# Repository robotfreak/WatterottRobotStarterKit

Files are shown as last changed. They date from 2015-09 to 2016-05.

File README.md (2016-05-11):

# Watterott Robot Starter Kit v2 (de)

Arduino Bibliothek und Beispiele für das Watterott Robot Starter Kit v2

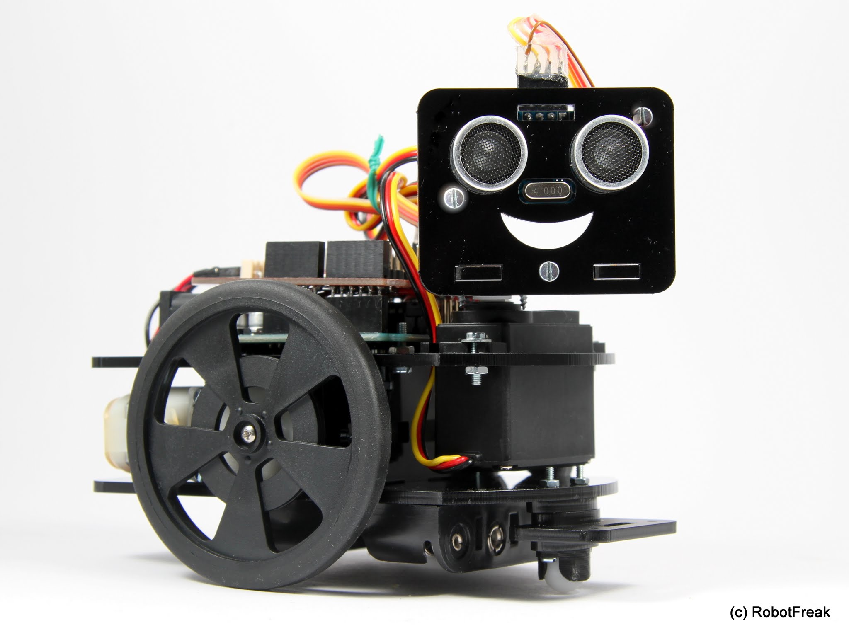
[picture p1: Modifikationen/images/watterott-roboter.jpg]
Watterott Roboter


## Basis Ausstattung:
* Watterott Starter Robot Kit (WSRK) Plexiglas Chassis, Motoren und Räder
* Arduino Uno 
* Arduino Motor Shield 
* Sharp GP2Y0A21YK0F Infrarot Distanz-Sensor an Pin A3
* Servo an Pin D5
* USB Kabel

## optionale Ausstattung:
* optional HC-SR04 Ultrascall Distanz Sensor an Pin D6, D7
* optional Pololu QTR-3A analoger Linien-Sensor an Pin A0,A1,A2
* optional Adafruit Bluefruit EZ-Link Modul
* Arduino Pro 5V anstelle Arduino Uno für einfachere Bluetooth Anbindung
* FTDI kompatibles USB serielles Modul/Kabel für Arduino Pro

## Modifikationen

* [Motoren entstören](Modifikationen/Motoren-Entstoeren-Mod.MD)
* [stärkere Motoren](Modifikationen/Staerkere-Motoren-Mod.MD)
* [Servo Stromversorgung](Modifikationen/Servo-Stromversorgungs-Mod.MD)
* [Sharp Stromversorgung](Modifikationen/Sharp-Sensor-Mod.MD)
* [Stromversorgung](Modifikationen/Stromversorgungs-Mod.MD)

## Erweiterungen

* [Ultraschall Sensor](Erweiterungen/Ultraschallsensor-Erweiterung.MD)
* [Linien Sensor](Erweiterungen/Liniensensor-Erweiterung.MD)
* [Bluetooth](Erweiterungen/Bluetooth-Erweiterung.MD)

## Links

Für weitere Informationen  über Erweiterungen oder Modifications des Watterott Starter Robot
besuchen sie: http://www.robotfreak.de

Für Informationen zum Kauf des Watterott Starter Robot Kit (WSRK)
besuchen sie:  http://www.watterott.com/de/StarterKit-Roboter

# Watterott Robot Starter Kit v2 (en)

Arduino Library &amp; Examples for the Watterott Robot Starter Kit v2

## Basic Parts:
* Watterott Starter Robot Kit (WSRK) acrylic chassis, motors and wheels
* Arduino Uno 
* Arduino Motor Shield 
* Sharp GP2Y0A21YK0F Infrared distance sensor connected to A3
* Servo connected to Pin D5
* USB cable

## Optional Parts:
* optional HC-SR04 Ultrasonic distance sensor connected to pin D6, D7
* optional Pololu QTR-3A analog Line sensor connected to A0,A1,A2
* optional Adafruit Bluefruit EZ-Link Module
* Arduino Pro 5V instead of Arduno Uno for easy Bluetooth connection
* FTDI compatible USB serial module/cable for Arduino Pro

## Modifikations

* [Motors](Modifikationen/Motoren-Entstoeren-Mod.MD)
* [More powerfull motors](Modifikationen/Staerkere-Motoren-Mod.MD)
* [Servo power supply](Modifikationen/Servo-Stromversorgungs-Mod.MD)
* [Sharp power supply](Modifikationen/Sharp-Sensor-Mod.MD)
* [Power supply](Modifikationen/Stromversorgungs-Mod.MD)

## Expansions

* [Ultrasonic sensor](Erweiterungen/HC-SR04-Erweiterung.MD)
* [Line sensor](Erweiterungen/Liniensensor-Erweiterung.MD)
* [Bluetooth](Erweiterungen/Bluetooth-Erweiterung.MD)

## Links

For information about expansions or modifications of the Watterott Starter Robot
visit http://www.robotfreak.de for more information

For information about buying the Watterott Starter Robot Kit (WSRK)
visit http://www.watterott.com/de/StarterKit-Roboter

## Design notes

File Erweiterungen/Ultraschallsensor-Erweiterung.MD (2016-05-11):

# Ultraschallsensor Erweiterung

Der Ultraschall Sensor kann anstelle des Sharp Infrarotsensors eingesetzt werden. Der Sensor hat einen breiteren Erfassungswinkel. Auf das Scannen der Umgebung mit dem Servo kann weitestgehend verzichtet werden.

## Was wird benötigt?

* HC-SR04 Ultraschallsensor
* 4-polige Buchsenleisten
* 4-polige Stiftleiste
* 4 Drähte 15cm lang
* Plexiglas Halterung (im Roboter Starer Kit enthalten)
* Lötkolben, Seitenschneider

## Durchführung

Der Sensor wird gemäß Verdrahtungs Schema verdrahtet und mit der Plexiglas Halterung am Servo Horn befestigt

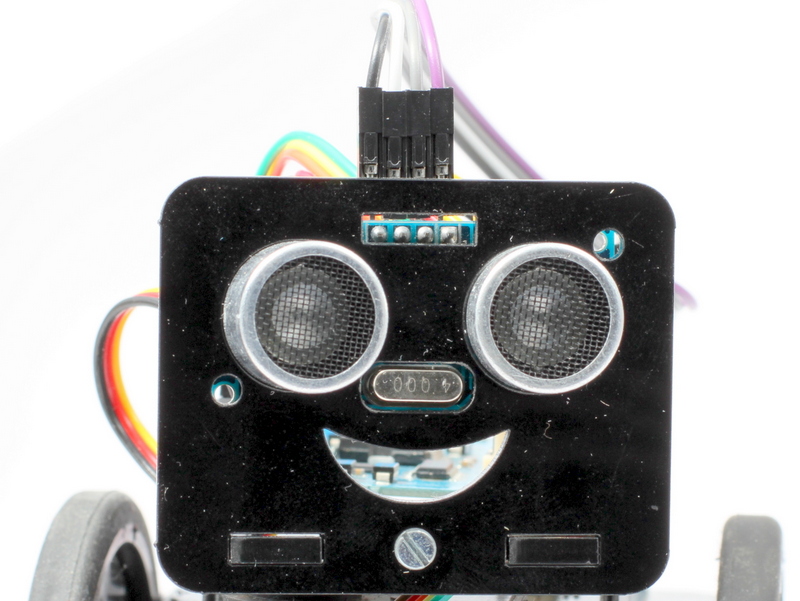
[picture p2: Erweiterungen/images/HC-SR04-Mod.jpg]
Sensor


## Verdrahtung

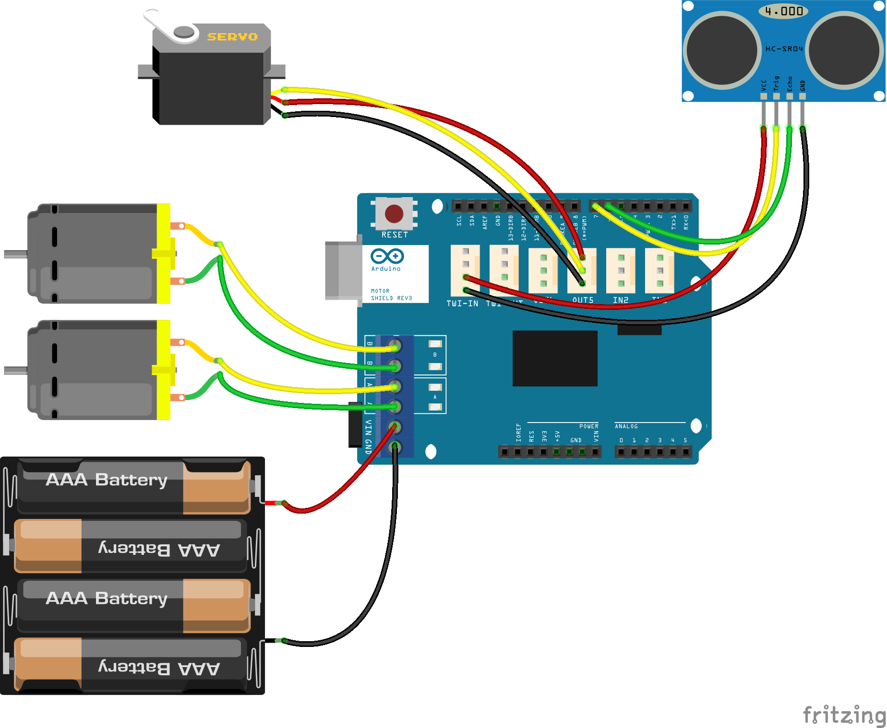
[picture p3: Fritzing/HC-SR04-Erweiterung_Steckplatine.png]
Verdrahtung


## Arduino Sketch

Die Funktionen zum Auslesen des Sensors sind Teil der Watterott Roboter Starter Kit (WRSK) Bibliothek.

Das Beispiel Sketch zum Kollionsvermeider (examples/ObstacleAvoiding) 

```arduino
/*
  ObstacleAvoiding.ino - Watterott Starter Robot Kit (WSRK)
  Author: RobotFreak www.robotfreak.de/blog
  Copyright (c) 2015 RobotFreak All Rights Reserved
 
  For information about the Watterott Starter Robot Kit (WSRK)
  visit http://www.watterott.com/de/StarterKit-Roboter
 
  The minimum circuit:
  * Watterott Starter Robot Kit (WSRK) Arduino Uno + Arduino Motor Shield 
  * Sharp GP2D12 or GP2D120 Infrared distance sensor connected to A3
  * or HC-SR04 Ultrasonic distance sensor connected to pin 6, 7
  * USB cable

  Alternative circuit:
  * Watterott Starter Robot Kit (WSRK) Arduino Pro + Arduino Motor Shield 
  * FTDI compatible USB serial module/cable
  * Sharp GP2D12 or GP2D120 Infrared distance sensor connected to A3
  * or HC-SR04 Ultrasonic distance sensor connected to pin 6, 7
  * optional Adafruit Bluefruit EZ-Link Module connected to FTDI connector

 */
#include <inttypes.h>
#include <Servo.h>
#include "iomapping.h"
#include <WRSK_UltrasonicSensor.h>
#include <WRSK_MotorControl.h>

#define DEBUG_LEVEL 2

#define LOW_SPEED 50
#define MID_SPEED 70
#define TOP_SPEED 100

WRSK_MotorControl motors( m1DirectionControl, m1SpeedControl, m2DirectionControl, m2SpeedControl, DEBUG_LEVEL);
WRSK_UltrasonicSensor us(usEchoPin, usTriggerPin, DEBUG_LEVEL);

int speed_l;
int speed_r;
int dly;
float distance;
int debugLevel = DEBUG_LEVEL;

Servo SensorServo;  // Mit diesem Element wird der Servo gesteuert

void setup() {

  Serial.begin(38400);                 // Sets the baud rate to 38400
  speed_l = 0;
  speed_r = 0;
  // Servo initialiseren und auf 90° stellen
  SensorServo.attach( servoPin );
  SensorServo.write( 90 );
  delay( 500 );

  Serial.println("WMR-SHR obstacle Avoiding Version 1.0");   

  distance = us.read();  // get distance
  while (distance > 10.0)
  {
    distance =  us.read();  // get distance
    delay(100);
  }
  Serial.println("Let's go");
}

void loop()
{
  int i;

  distance =  us.read();  // get distance

  if (distance > 0.0)
  {
    if (distance <= 10.0)
    {
      motors.driveWheels(0,0);
      delay(500);
      speed_l = -MID_SPEED;
      speed_r = MID_SPEED;
      dly = 5;
      do {
        distance =  us.read();  // get distance
        delay(40);
        motors.driveWheels(speed_l, speed_r);
        //      motors.driveWheelsRamp(speed_l, speed_r, dly);
      } 
      while(distance < 20.0);  
      speed_l = 0;
      speed_r = 0;
      motors.driveWheels(speed_l,speed_r);
      //    motors.driveWheelsRamp(speed_l, speed_r, dly);
      delay(500);
    }
    else if (distance < 30.0)
    {
      speed_l = MID_SPEED;
      speed_r = MID_SPEED;
    }
    else
    {
      speed_l = TOP_SPEED;
      speed_r = TOP_SPEED;
    }
    dly = 10;
    motors.driveWheels(speed_l, speed_r);
    //  motors.driveWheelsRamp(speed_l, speed_r, dly);
  }

  delay(40);

}
```

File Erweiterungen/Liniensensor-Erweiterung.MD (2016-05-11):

# Liniensensor Erweiterung

Mit dieser  Erweiterung kann der Roboter einen schwarzen Linie auf weißem Unterrund folgen

## Was wird benötigt?

* Pololu QTR-3A Liniensensor (analog)
* 5 polige Buchsenleiste 
* 5 polige Stiftleiste 
* 2 polige Stiftleiste 
* 2 Schrauben M2x15, 4 Muttern M2
* Lötkolben, Seitenschneider, Dremel
* schwarzes Isolier Klebeband 10mm breit
* Plexiglas Halterung (im Roboter Kit enthalten)

## Durchführung

* Es müssen die beiden Lötbrücken SNS1 und SNS2 am Motor Shield entfernt werden.
* Die Verbindung Sensor / Arduino Shield erfolgt mit den Drähten, Buchsen- und Stiftleisten
* Der Sensor wird mit den M2 Schrauben und Muttern und der Plexiglas Halterung am Roboter Starter Kt befestigt 

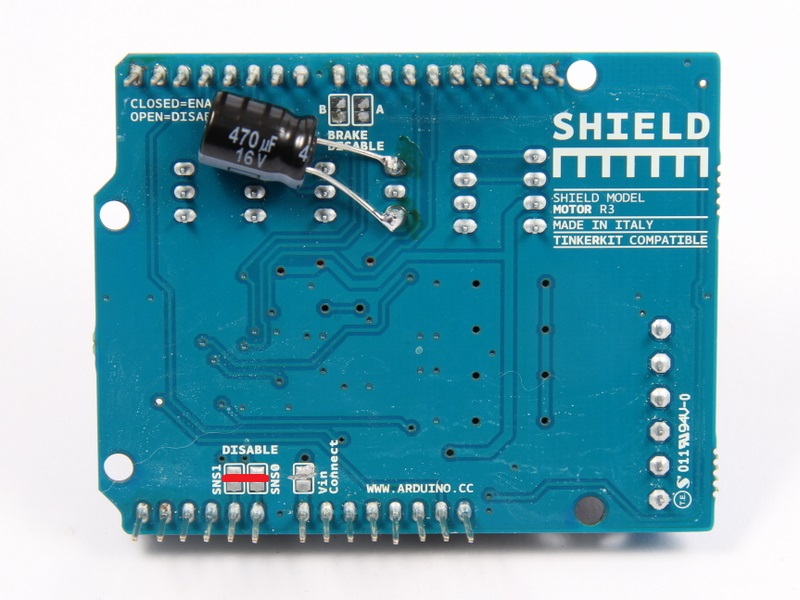
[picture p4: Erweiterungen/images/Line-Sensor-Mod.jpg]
Motorshield Mod

 
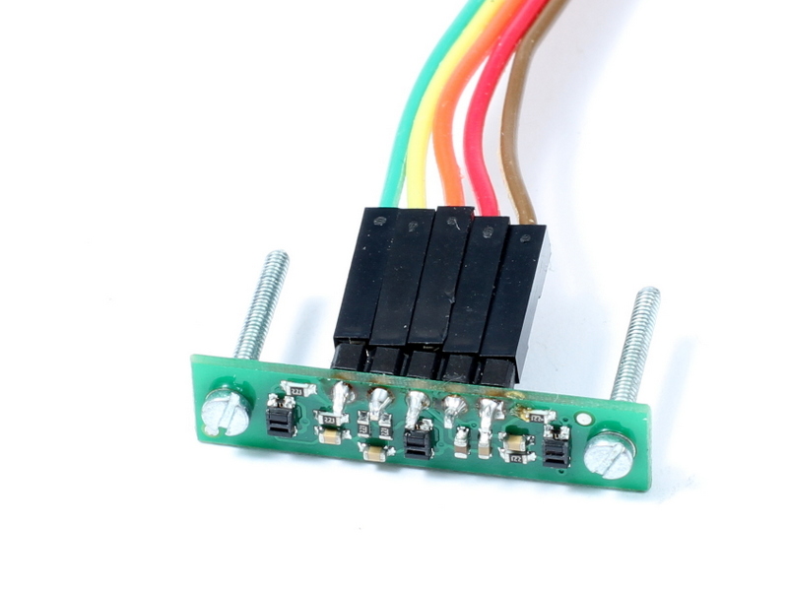
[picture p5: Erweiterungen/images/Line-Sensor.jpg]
Sensor Linien-Sensor


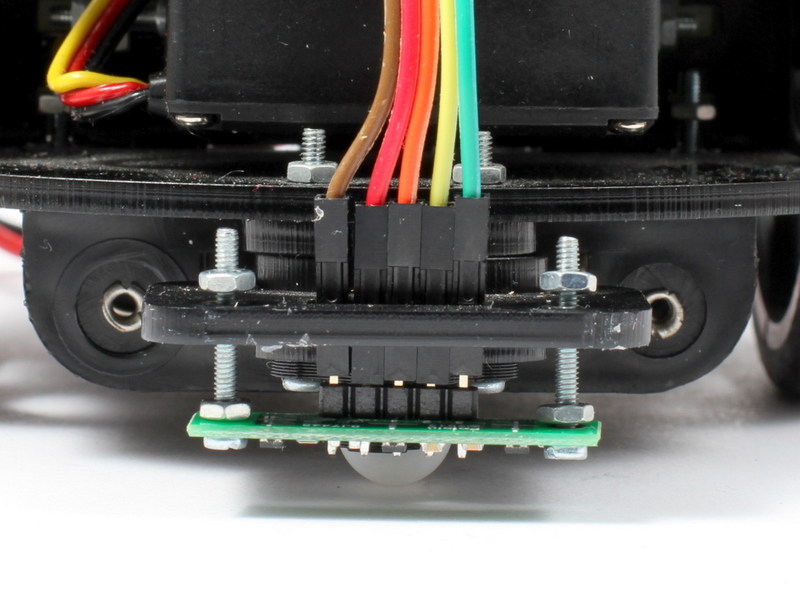
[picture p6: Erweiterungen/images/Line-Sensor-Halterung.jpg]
Sensor Halterung


## Verdrahtung

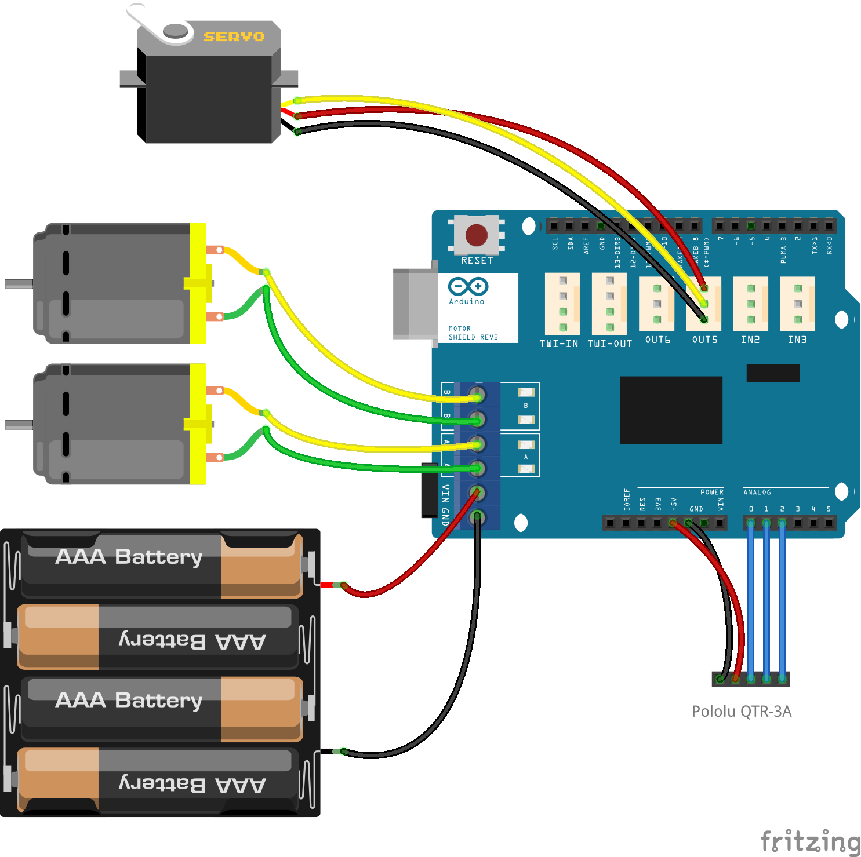
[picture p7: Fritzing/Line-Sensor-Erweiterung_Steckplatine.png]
Verdrahtung


## Arduino Sketch

Es wird die Pololu QTR Bibliothek benötigt: https://github.com/pololu/qtr-sensors-arduino

```arduino
/*
 LineFollower.ino - Watterott Starter Robot Kit (WSRK) line follower
 
  Author: RobotFreak www.robotfreak.de/blog
  Copyright (c) 2015 RobotFreak All Rights Reserved
 
  For information about the Watterott Starter Robot Kit (WSRK)
  visit http://www.watterott.com/de/StarterKit-Roboter

  The minimum circuit:
  * Watterott Starter Robot Kit (WSRK) Arduino Uno + Arduino Motor Shield 
  * Pololu QTR-3RC or QTR-3A Line sensor connected to A0,A1,A2
  * HC-SR04 Ultrasonic distance sensor connected to pin 6, 7
  * USB cable

  Alternative circuit:
  * Watterott Starter Robot Kit (WSRK) Arduino Pro + Arduino Motor Shield 
  * FTDI compatible USB serial module/cable
  * Pololu QTR-3RC or QTR-3A Line sensor connected to A0,A1,A2
  * optional Adafruit Bluefruit EZ-Link Module connected to FTDI connector
 
*/
#include <Servo.h>
#include <QTRSensors.h>
#include <PID_v1.h>
#include "iomapping.h"
#include <WRSK_UltrasonicSensor.h>
#include <WRSK_SharpSensor.h>
#include <WRSK_MotorControl.h>

#define LOW_SPEED 50
#define MID_SPEED 70
#define TOP_SPEED 100

#define BUFFERSIZE 20
#define DEFAULT_speedMultiplier 5 
//#define USE_BLUETOOTH_SERIAL2    // we use Bluetooth over Serial2

// ** GENERAL SETTINGS ** - General preference settings
#define DEBUG_LEVEL 2
int debugLevel = DEBUG_LEVEL;
boolean DEBUGGING = true; // Whether debugging output over serial is on by defauly (can be flipped with 'h' command)

WRSK_MotorControl motors( m1DirectionControl, m1SpeedControl, m2DirectionControl, m2SpeedControl, DEBUG_LEVEL);

int speedMultiplier = DEFAULT_speedMultiplier; // Default speed setting. Uses a range from 1-10 

// No config required for these parameters
unsigned long stopTime=millis(); // used for calculating the run time for motors

//Define Variables we'll be connecting to
double Setpoint, Input, Output;

//Define the aggressive and conservative Tuning Parameters
double aggKp=4, aggKi=0.2, aggKd=1;
double consKp=1, consKi=0.0, consKd=0.0;
//double consKp=1, consKi=0.05, consKd=0.25;

//Specify the links and initial tuning parameters
PID myPID(&Input, &Output, &Setpoint, consKp, consKi, consKd, DIRECT);

Servo myServo;

void setup() 
{
  myServo.attach(servoPin);
  myServo.write(90);

  Serial.begin(38400);
#ifdef USE_BLUETOOTH_SERIAL2
  Serial2.begin(115200);
#endif
  if (debugLevel) { Serial.println("MURCS Line Follower V1.0");  }
  initLineFollow();
//  initLineFollowPID();
  
} 

// Stop the bot
void stopBot() 
{
  motors.driveWheels(0,0);
  if (debugLevel){ Serial.println("Stopping both wheels"); 
  }
  serialReply("i", "st"); // Tell the phone that the robot stopped
}

// sensors 0 through 2 are connected to analog inputs 0 through 2, respectively
QTRSensorsRC qtr((unsigned char[]) {line1Pin, line2Pin, line3Pin}, 
  NUM_LINESENSORS);
unsigned int sensorValues[NUM_LINESENSORS];

void initLineSensors(int debugLevel)
{
  delay(1000);
  for (int i = 0; i < 10; i++)  // make the calibration take about 1.25 seconds
  {
    qtr.calibrate();       // reads all sensors 10 times at 2.5 ms per six sensors (i.e. ~25 ms per call)
    motors.driveWheels(-LOW_SPEED,LOW_SPEED);
  }
  motors.driveWheels(0,0);
  delay(500);
  for (int i = 0; i < 15; i++)  // make the calibration take about 2.5 seconds
  {
    qtr.calibrate();       // reads all sensors 10 times at 2.5 ms per six sensors (i.e. ~25 ms per call)
    motors.driveWheels(LOW_SPEED,-LOW_SPEED);
  }
  motors.driveWheels(0,0);
  delay(500);
  for (int i = 0; i < 10; i++)  // make the calibration take about 1.25 seconds
  {
    qtr.calibrate();       // reads all sensors 10 times at 2.5 ms per six sensors (i.e. ~25 ms per call)
    motors.driveWheels(-LOW_SPEED,LOW_SPEED);
  }
  motors.driveWheels(0,0);
  delay(500);
  // print the calibration minimum values measured when emitters were on
  if (debugLevel > 1)
  {
    for (int i = 0; i < NUM_LINESENSORS; i++)
    {
      Serial.print(qtr.calibratedMinimumOn[i]);
      Serial.print(' ');
    }
    Serial.println();
  
    // print the calibration maximum values measured when emitters were on
    for (int i = 0; i < NUM_LINESENSORS; i++)
    {
      Serial.print(qtr.calibratedMaximumOn[i]);
      Serial.print(' ');
    }
    Serial.println();
    Serial.println();
  }
  delay(1000);
}

unsigned int  readLineSensors(int debugLevel)
{
  // read calibrated sensor values and obtain a measure of the line position from 0 to 5000
  // To get raw sensor values, call:
  //  qtra.read(sensorValues); instead of unsigned int position = qtra.readLine(sensorValues);
  unsigned int position;
  static int count = 0;

//  qtr.read(sensorValues);
  position = qtr.readLine(sensorValues);
  
  if (debugLevel > 1)
  {
  // print the sensor values as numbers from 0 to 1000, where 0 means maximum reflectance and
  // 1000 means minimum reflectance, followed by the line position
    for (unsigned char i = 0; i < NUM_LINESENSORS; i++)
    {
      Serial.print(sensorValues[i]);
      Serial.print('\t');
    }
    //Serial.println(); // uncomment this line if you are using raw values
    Serial.println(position); // comment this line out if you are using raw values
  }
  if (count > 10)
  {
//    Serial2.write((position >> 8) & 0xFF);
//    Serial2.write(position & 0xFF);
    count = 0;
  }
  return position;
}

void initLineFollow()
{
//  myServo.write(90);
  initLineSensors(debugLevel);
}

void initLineFollowPID()
{
//  myServo.write(90);
  initLineSensors(debugLevel);
  Input = 0.0;
  Setpoint = 0.0;
  //tell the PID to range between -50 and 50 
  myPID.SetOutputLimits(-2000, 2000); 
  //turn the PID on
  myPID.SetMode(AUTOMATIC);
}

// Replies out over serial and handles pausing and flushing the data to deal with Android serial comms
void serialReply(char* sensorname, char* tmpmsg) 
{
#ifdef USE_BLUETOOTH_SERIAL2
  Serial2.print(sensorname);
  Serial2.print(":");
  Serial2.println(tmpmsg); // Send the message back out the serial line
  //Wait for the serial debugger to shut up
  delay(200); //this is a magic number
  Serial2.flush(); //clears all incoming data
#else
  Serial.print(sensorname);
  Serial.print(":");
  Serial.println(tmpmsg); // Send the message back out the serial line
  //Wait for the serial debugger to shut up
  delay(200); //this is a magic number
  Serial.flush(); //clears all incoming data
#endif
}

// Check if enough time has elapsed to stop the bot and if it is safe to proceed
void checkIfStopBot() 
{
  if (stopTime < millis()) 
  {
    stopBot();
  }
}

void doLineFollow()
{
  int speed_l, speed_r;
  unsigned int position;

  position = readLineSensors(debugLevel);

  if (position < 500)
  {  // far to the right                                    
    if (debugLevel > 2) { Serial.println("far to the right");}
    speed_l = MID_SPEED;
    speed_r = -LOW_SPEED;
  }
  else if (position > 1500)
  {  // far to the left
    if (debugLevel > 2) { Serial.println("far to the left");}
    speed_l = -LOW_SPEED;
    speed_r = MID_SPEED;
  }
  else
  {  // centered on line 
    if (debugLevel > 2) { Serial.println("on line");}
    speed_l = MID_SPEED;
    speed_r = MID_SPEED;
  }
  stopTime = motors.driveWheels(speed_l, speed_r);
  delay(20); 
}

void doLineFollowPID()
{
  int speed_l, speed_r, speedDiff;
  int position;

  position = readLineSensors(0);
  Input = position - 2000.0;
  myPID.Compute();

  speedDiff = map(abs((int)Output), -2000, 2000, -50, 50);
//  if (Output < 0.0)
//  speedDiff = -speedDiff;
  if (debugLevel > 1) 
  {
    Serial.print("Input: ");
    Serial.print(Input, DEC);
    Serial.print(" Output: ");
    Serial.print(Output, DEC);
    Serial.print(" SDiff: ");
    Serial.println(speedDiff, DEC);
  }
//  speedDiff = (int) power_difference;
  // Compute the actual motor settings.  We never set either motor
  // to a negative value.
  const int max = TOP_SPEED;
  if(speedDiff > max)
      speedDiff = max;
  if(speedDiff < -max)
      speedDiff = -max;
 
  if(speedDiff < 0)
     stopTime = motors.driveWheels(max+speedDiff, max);
  else
     stopTime =  motors.driveWheels(max, max-speedDiff);
  delay(40); 
}

// Main loop running at all times
void loop() 
{
  doLineFollow();
  checkIfStopBot();
}
```

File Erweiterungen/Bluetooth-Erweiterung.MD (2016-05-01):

# Bluetooth Erweiterung

Die Bluetooth Erweiterung ermöglicht die Fernbedienung des Roboter über Bluetooth. Mit dem Adafruit BLuetooth EZ-Link ist es auch möglich, den Arduino über Bluetooth zu programmieren.

## Was wird benötigt?

* Adafruit Bluetooth EZ Link Modul
* Arduino Pro 5V/16MHz
* oder 10polige Stiftleiste, 100nF Kondensator für Arduino Uno

## Durchführung

Leider funktioniert dies Erweiterung nicht so ohne weiteres mit dem Arduino Uno. Einfacher geht es mkt einem Arduino Pro. Dort kann man einfach das Bluetooth Modul an der 6-poligen FTDI -Stiftleite anstecken. fertig.

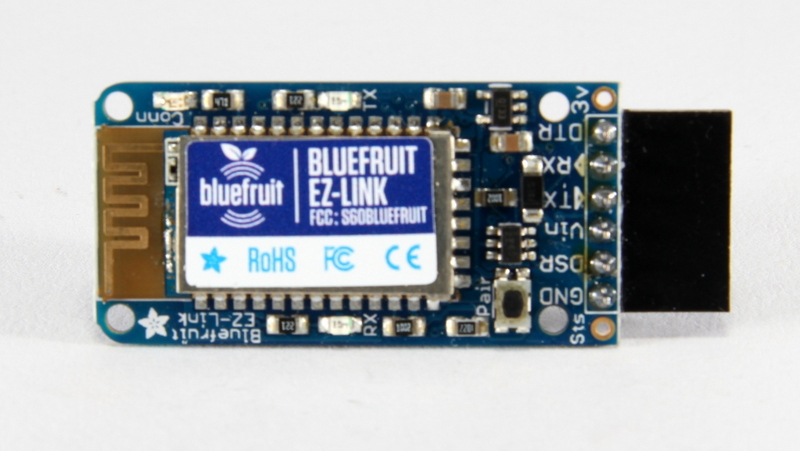
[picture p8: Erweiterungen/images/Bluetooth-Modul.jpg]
Bluetooth Bluetooth Modul


## Verdrahtung Arduino Pro

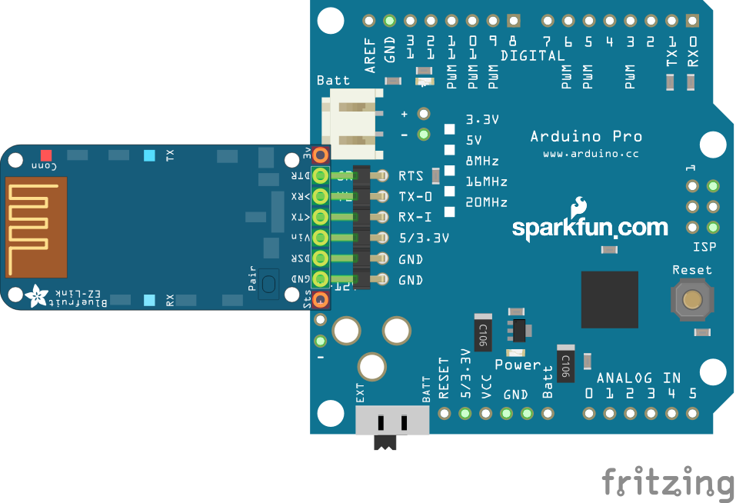
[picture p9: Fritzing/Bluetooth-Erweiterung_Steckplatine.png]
Verdrahtung Pro Verdrahtung Arduino Pro


## Verdrahtung Arduino Uno

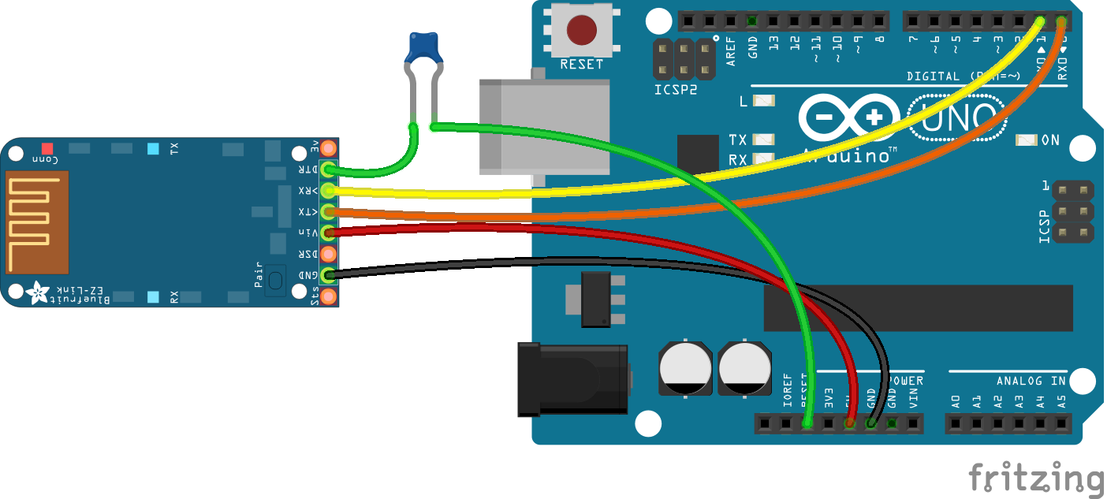
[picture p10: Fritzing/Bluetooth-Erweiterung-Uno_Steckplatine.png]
Verdrahtung Uno Verdrahtung Arduino Uno


## Arduino Sketch

t.b.c

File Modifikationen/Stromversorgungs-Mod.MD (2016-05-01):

#Stromversorgungs Modifikation

Bei dieser Variante wird die Batteriespannung mit Hilfe eines Step-Up Wandlers auf einen Wert im empfohlenen Eingangsbereich hochgeregelt und stabilisiert. Umbauten am Motor-Shield sind nicht notwendig. Ein geeigneter Step-Up Wandler ist z.B. der LM2577. Diesen gibt als fertiges Modul auf eBay, DealExtreme oder Amazon. Der Wandler generiert aus einer Eingangsspannung im Bereich von 3..30V eine regelbare Ausgangsspannung von 4..30V. Bei einem <a href="http://de.wikipedia.org/wiki/Aufw%C3%A4rtswandler">Aufwärtswandler</a> wird niedrige Eingangsspannung in eine höhere Ausgangsspannung gewandelt. Achtung, die Module können sehr leicht verwechselt werden mit Step-Down Wandlern mit LM2596 IC. Das sind <a href="http://de.wikipedia.org/wiki/Abw%C3%A4rtswandler">Abwärtswandler</a>, die aus einer größeren Eingangsspannung eine kleinere Ausgangsspannung machen.

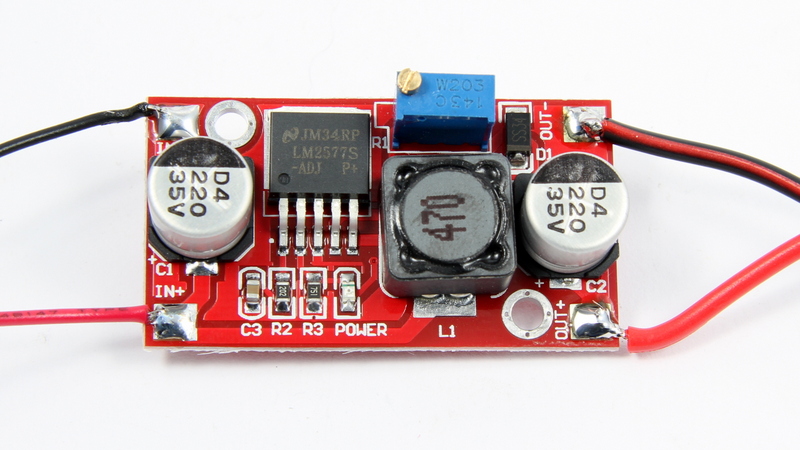
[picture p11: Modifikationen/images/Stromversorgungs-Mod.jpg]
LM2577-Modul


Der Step-Up Wandler wird zwischen Batteriefach und der Stromversorgung für das Motor Shield mit eingebaut. Bei der Gelegenheit sollte man auch gleich einen Kippschalter zum Ein-/Ausschalten des Roboters  mit einbauen. Der Step-Up Wandler wird vor dem Anschließen an das Moto-Shield, mit Hilfe des Potentiometer auf eine Ausgangsspannung von 7.5V eingestellt. Zum einen liegt dieser Wert im empfohlenen Spannungsbereich von 7..12V für das Arduino Board und Motor Shield. Zum anderen fallen am Motor Treiber ca. 1.5V  ab, während die Motoren selbst für 6V ausgelegt sind. Dadurch liegt der ideale Wert bei 7.5V. Das Step-Up Wandler Modul passt noch sehr gut auf die Unterseite des Roboters hinter das Batteriefach. Einfach mit Heißkleber festkleben.

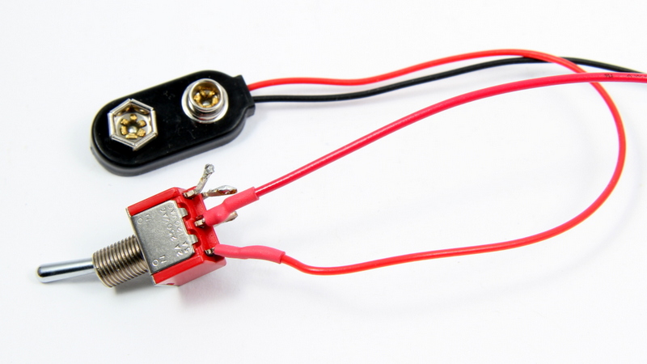
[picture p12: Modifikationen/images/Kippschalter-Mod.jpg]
Kippschalter


##Benötigte Bauteile:

* <a href="http://www.amazon.de/SainSmart-Step-up-Adjustable-Converter-3-5-30V/dp/B00KY0LW0S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">SainSmart LM2577 Power StepUp Converter</a>
* <a href="http://www.reichelt.de/Kippschalter/MS-500A/3/index.html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">optionaler Kippschalter</a>
* 10cm isolierter Draht 2 x rot, 1 x schwarz

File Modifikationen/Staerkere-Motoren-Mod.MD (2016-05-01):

#stärkere Motoren

Etwas mehr Motorleistung gefällig? Hier kommt der Tuning Tip für mehr Power. Die in den Getriebmotoren verbauten Gleichstrom Motoren sind vom Typ 130, eine gängige Größe für Motoren, die auch in vielen Spielzeug Modellen steckt. Statt der braven, stromsparenden Variante, wie sie im GM9 Getriebemotor verwendet werden, gibt es auch noch eine leistungsfähigere <a href="http://www.watterott.com/de/Brushed-DC-Motor-130-Size-6V-115kRPM-800mA-Stall">Power Variante</a>. Damit läuft der kleine Roboter gleich mal ordentlich schneller. Natürlich auf Kosten einer größeren Stromaufnahme, sprich die Akkus/Batterien sind schneller leer.

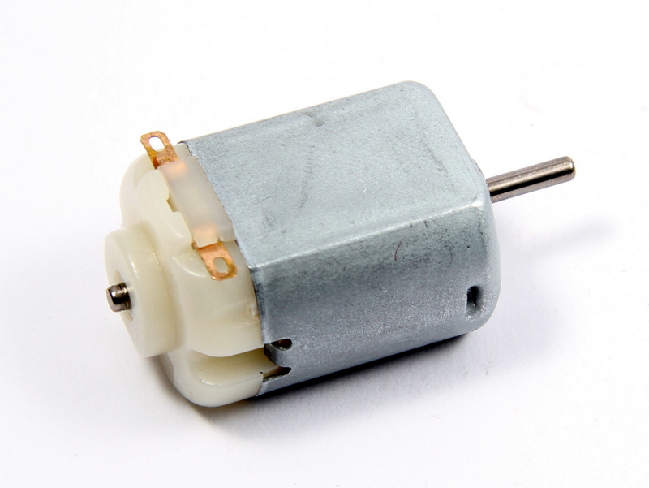
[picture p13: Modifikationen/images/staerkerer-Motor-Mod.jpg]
Motor


Für den Umbau werden die alten Motoren vom Getriebe entfernt. Die Motoren werden nur von einer Plastiklasche gehalten. Entfernt man diese vorsichtig, kann man die Motoren herausziehen. Das Motor-Ritzel lässt sich leicht mit einer Zange vom Motor abziehen und auf den neuen stärkeren Motor aufstecken. Den Motor wieder zurück in das Getriebe stecken und mit der Plastiklasche fixieren. Voila.

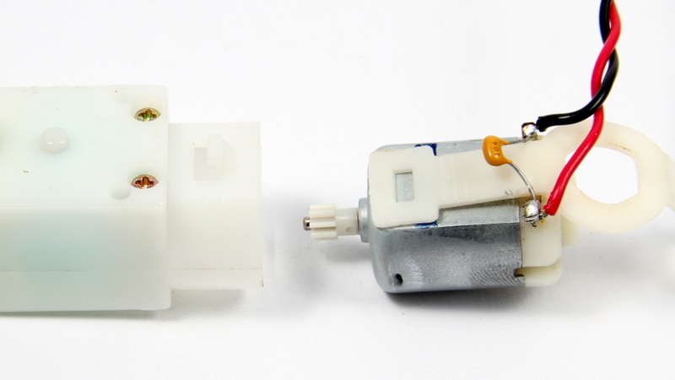
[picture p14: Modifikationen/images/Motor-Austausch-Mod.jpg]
Motor-Austausch


##Benötigte Bauteile:

* 2 x <a href="http://www.watterott.com/de/Brushed-DC-Motor-130-Size-6V-115kRPM-800mA-Stall">Watterott Brushed DC Motor 130-size 800mA stall</a>
* 2 x <a href="http://www.exp-tech.de/dc-buerstenmotor-130-size-6v-11-5krpm-800ma-stall">alternativ Exp-Tech Brushed DC Motor 130-size 800mA stall</a>

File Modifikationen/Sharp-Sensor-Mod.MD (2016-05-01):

#Sharp Sensor Modifikation

Der Infrarot Sensor (Sharp GP2Y0A21YK0F) ist eine preiswerte Möglichkeit um Entfernungen zu Objekten zu messen, die sich vor dem Roboter befinden. Leider ist das Ausgangssignal dieser Sensoren nicht sehr stabil und gibt daher keine genauen Werte zurück. Das Problem ist die Stromversorgung des Sensors. Das hatte ich ja schon mal vor einiger Zeit <a href="http://www.robotfreak.de/blog/robotik/sharp-ir-sensor-ausgabe-verbessern/479">geblogged</a>. Auch hier helfen Kondensatoren,die Störungen zu eliminieren. Dazu sind allerdings 2 Kondensatoren notwendig. Ein kleiner Keramik Kondensator von 100nF wie bei den Motoren für die kleinen Peaks und ein großer dicker Elektrolyt Kondensator von 100µF für die groben Schwankungen des Ausgangssignals. Am besten sind dafür SMD Bauteile geeignet. Durch die geringe Bauteilgröße passen diese Kondensatoren direkt an die Stromversorgungspins des Sensors. Die Kondensatoren müssen so nahe wie möglich am Sensor angebracht werden.

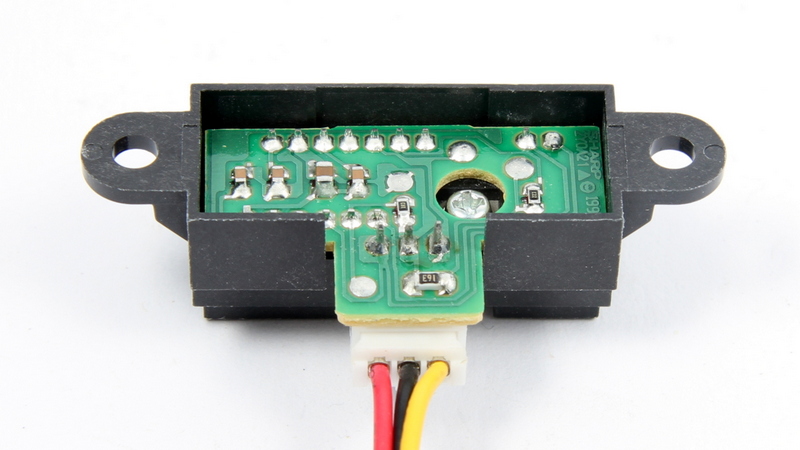
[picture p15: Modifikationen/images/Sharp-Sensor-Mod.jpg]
Sharp-Sensor


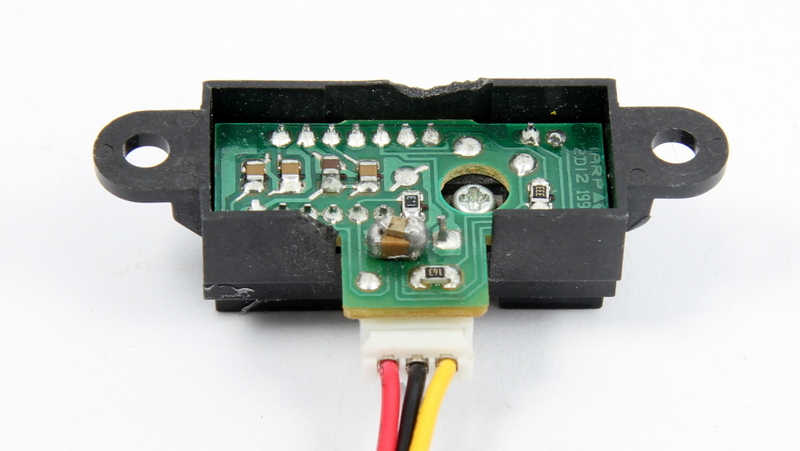
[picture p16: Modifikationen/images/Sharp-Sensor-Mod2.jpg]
Sharp-Sensor-Modifikation


##Benötigte Bauteile:

* 1 x <a href="http://www.reichelt.de/Vielschicht-SMD-G0805/X7R-G0805-100N/3//index.html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">100nF SMD 0805 Vielschichtkondensator </a>
* 1 x <a href="http://www.reichelt.de/Vielschicht-SMD-G1206-High-Cap/X5R-G1206-100-6/3//index.html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">100µF SMD 1206 Vielschichtkondensator </a>

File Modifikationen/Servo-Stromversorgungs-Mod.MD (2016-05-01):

#Servo Spannungsversorgung Modifikation

Der Servo für den Front-Sensor ist eine weitere Störquelle. Beim Anfahren zieht er besonders viel Strom, was zu kurzen Spannungseinbrüchen führen kann. Da die 4 AA Zellen eh schon zu knapp bemessen sind für einen sicheren Betrieb, kann dies zu einem Reset des Arduino Boards führen. Abhilfe ist auch hier durch einen Elektrolyt Kondensator (Elko) von 470..1000µF möglich, der in die Versorgungsleitung zum Servo gehängt wird. Dieser versorgt den Servo mit dem nötigen Strom, ohne das es größere Spannungseinbrüche gibt.

Der Elko wird auf die Rückseite des Motor Shields auf die Anschlüsse von Out ~6 gelötet. Dabei muss die Polung des Elkos berücksichtigt werden. 

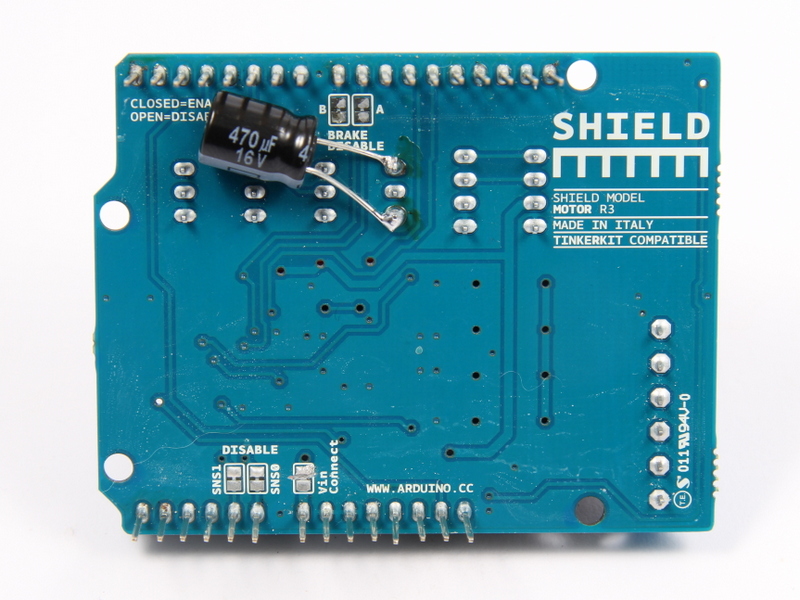
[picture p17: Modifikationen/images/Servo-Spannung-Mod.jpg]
Servospannung


##Benötigte Bauteile:

* <a href="http://www.reichelt.de/Elkos-radial-105-C-1000-5000h/RAD-FC-1-000-10/3//index.html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">Elko radial, 105°C, low ESR, 1000µF, 10V</a

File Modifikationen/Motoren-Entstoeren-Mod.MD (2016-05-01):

#Motoren entstören

Die Motoren des Starter Kits sind Gleichstrom Getriebemotoren (Solarbotics GM9). Die Bürsten der Gleichstrommotoren erzeugen ordentlich Störungen auf den elektrischen Verbindungen und können auch andere Elektronik, insbesondere Sensoren beeinflussen. Grundsätzlich  sollten Motoren entstört werden, egal ob Störungen auftreten oder nicht. Dazu wird je Motor ein Keramik-Kondensatoren (KerKo) mit ca. 100nF benötigt. Dieser Kondensator wird einfach parallel über die Motoranschlüsse gelötet.

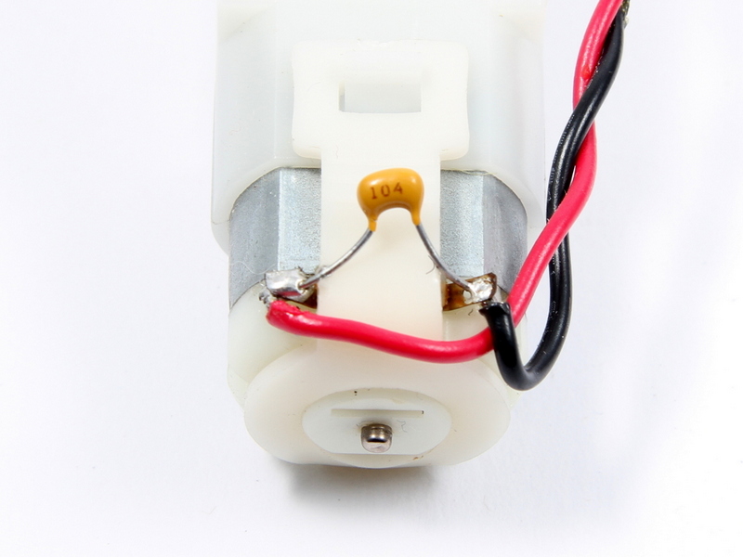
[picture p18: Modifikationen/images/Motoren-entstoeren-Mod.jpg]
Entstoerung


##Benötigte Bauteile:

* 2 x <a href="http://www.reichelt.de/Vielschicht-bedrahtet-Z5U-20-/Z5U-2-5-100N/3//index.html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">100nF Keramik-Kondensatoren</a>

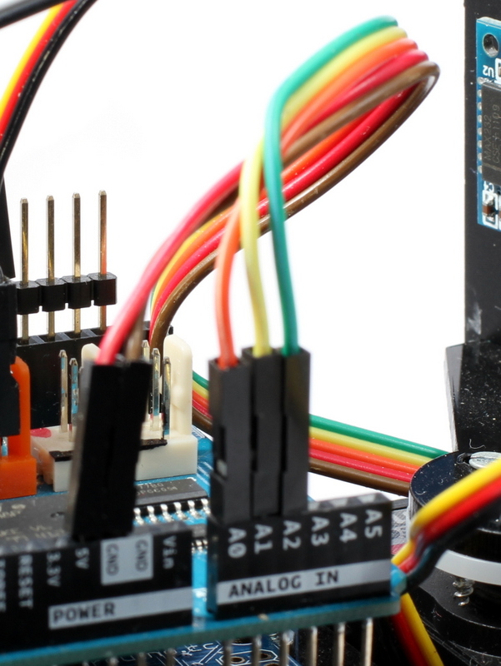
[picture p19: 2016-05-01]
Erweiterungen/images/Line-Sensor-Verdrahtung.jpg

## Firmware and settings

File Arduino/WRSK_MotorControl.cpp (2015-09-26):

#if defined(ARDUINO) && ARDUINO >= 100
#include "Arduino.h"
#else
#include "WProgram.h"
#endif


#include "WRSK_MotorControl.h"

WRSK_MotorControl::WRSK_MotorControl(void)
{
  this->dirPin1 = 3;
  this->pwmPin1 = 12;
  this->brkPin1 = 9;
  this->dirPin2 = 13;
  this->pwmPin2 = 11;
  this->brkPin2 = 8;
  this->useBrake = true;
  this->dbgLevel = 0;
  initMotorControl();
} 

WRSK_MotorControl::WRSK_MotorControl(int _dirPin1, int _pwmPin1, int _dirPin2, int _pwmPin2, int _dbgLevel)
{
  this->dirPin1 = _dirPin1;
  this->pwmPin1 = _pwmPin1;
  this->dirPin2 = _dirPin2;
  this->pwmPin2 = _pwmPin2;
  this->useBrake = false;
  this->dbgLevel = _dbgLevel;
  initMotorControl();
} 

WRSK_MotorControl::WRSK_MotorControl(int _dirPin1, int _pwmPin1, int _brkPin1, int _dirPin2, int _pwmPin2, int _brkPin2, int _dbgLevel)
{
  this->dirPin1 = _dirPin1;
  this->pwmPin1 = _pwmPin1;
  this->brkPin1 = _brkPin1;
  this->dirPin2 = _dirPin2;
  this->pwmPin2 = _pwmPin2;
  this->brkPin2 = _brkPin2;
  this->dbgLevel = _dbgLevel;
  this->useBrake = false;
  initMotorControl();
} 

void WRSK_MotorControl::initMotorControl(void)
{
  pinMode(this->dirPin1, OUTPUT);
  pinMode(this->dirPin2, OUTPUT);
  pinMode(this->pwmPin1, OUTPUT);
  pinMode(this->pwmPin2, OUTPUT);
  if (this->useBrake == true)
  {
    pinMode(this->brkPin1, OUTPUT);
    pinMode(this->brkPin2, OUTPUT);
    digitalWrite(this->brkPin1, LOW);
    digitalWrite(this->brkPin2, LOW);
  }
  analogWrite(this->pwmPin1, 0);
  analogWrite(this->pwmPin2, 0);
  maxRunTime = 2000;
}


// Drive DC motors to move the robot using values in range -100 to 100 for left and right
unsigned long WRSK_MotorControl::driveWheels(int valueLeft, int valueRight) 
{

  // Set left motor pins to turn in the desired direction
  if (valueLeft < 0){
    digitalWrite(this->dirPin2,LOW);
  }
  else {
    digitalWrite(this->dirPin2,HIGH);
  }
  // Set right motor pins to turn in the desired direction
  if (valueRight < 0){
    digitalWrite(this->dirPin1,LOW);
  }
  else {
    digitalWrite(this->dirPin1,HIGH);
  }
  // Maps "w" values to the wider range that the motor responds to
  valueLeft = map(abs(valueLeft), 0, 100, 0, MAX_SPEED_LIMIT);
  valueRight = map(abs(valueRight), 0, 100, 0, MAX_SPEED_LIMIT);
  analogWrite(this->pwmPin2,valueLeft);
  analogWrite(this->pwmPin1,valueRight);

  return millis() + maxRunTime;
}

void WRSK_MotorControl::driveWheelsRamp(int speed1, int speed2, int dly)
{
  int temp_speed1 = last_speed1;
  int temp_speed2 = last_speed2;

  if (this->dbgLevel > 1)
  {
    Serial.print("MoveRamp: ");
    Serial.print(speed1, DEC);
    Serial.print(", ");
    Serial.print(speed2, DEC);
    Serial.print(", ");
    Serial.println(dly, DEC);
  }
  while ((speed1 != temp_speed1) ||
         (speed2 != temp_speed2))
   {
      if (temp_speed1 > speed1)
        temp_speed1--;
      else if (temp_speed1 < speed1)
        temp_speed1++;

      if (temp_speed2 > speed2)
        temp_speed2--;
      else if (temp_speed2 < speed2)
        temp_speed2++;
      driveWheels(temp_speed1, temp_speed2);
      delay(dly);
   }
}

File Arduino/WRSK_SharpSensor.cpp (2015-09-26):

#if defined(ARDUINO) && ARDUINO >= 100
#include "Arduino.h"
#else
#include "WProgram.h"
#endif

#include "WRSK_SharpSensor.h"

/*
 * sharpdistance.cpp Sharp GP2Dxx IR sensor functions
 * taken from https://code.google.com/p/rbots/
 *
 */

WRSK_SharpSensor::WRSK_SharpSensor(int _sensPin)
{
  this->sensType = SHARP_GP12;
  this->sensPin = _sensPin;
  this->dbgLevel = 0;
}

WRSK_SharpSensor::WRSK_SharpSensor(int _sensType, int _sensPin, int _dbgLevel)
{
  this->sensType = _sensType;
  this->sensPin = _sensPin;
  this->dbgLevel = _dbgLevel;
}

float WRSK_SharpSensor::read(void)
{
  if (this->sensType == SHARP_GP12)
    return readGP2D12Range(this->sensPin, this->dbgLevel);
  else if (this->sensType == SHARP_GP120)
    return readGP2D120Range(this->sensPin, this->dbgLevel);
  else
    return -1;
}

float WRSK_SharpSensor::readGP2D12Range(int pin, int debugLevel) 
{
  float val;
  int tmp;
  
  tmp = analogRead(pin);
  if(tmp < 3)
    return -1;  //invalid value
    
  val = (6787.0 / ((float)tmp - 3.0))-4.0;
  if (debugLevel > 1) 
  {
    Serial.print("Distance: ");
    Serial.print(val, DEC);
    Serial.println(" cm");
  }
  return val;
}

float WRSK_SharpSensor::readGP2D120Range(int pin, int debugLevel) 
{
  float val;
  int tmp;
  
  tmp = analogRead(pin);
  if(tmp < 3)
    return -1;  //invalid value
    
  val = (2914.0 / ((float)tmp + 5.0))-1.0;
  if (debugLevel > 1) 
  {
    Serial.print("Distance: ");
    Serial.print(val, DEC);
    Serial.println(" cm");
  }
  return val;
}

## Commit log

2015-09-26 WRSK inital release
    Arduino sources for the Watterott Robot Starter Kit
2015-09-26 Swap motor pwm, direction pins
    [AllInOne.ino, LineFollower.ino, MotorTest.ino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]
2016-05-01 Arduino Examples
    Arduino Examples moved to seperate folder. Added Erweiterungen and
    Modifikationen
    [Basis-Variante.fzz, Bluetooth-Erweiterung.fzz, HC-SR04-Erweiterung.fzz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]
2016-05-01 motor image added
2016-05-01 Bluetooth for Uno
    [Bluetooth-Erweiterung-Uno.fzz]
2016-05-11 Updated Fritzing Schematics
    [Basis-Variante.fzz, HC-SR04-Erweiterung.fzz, Line-Sensor-Erweiterung.fzz]
